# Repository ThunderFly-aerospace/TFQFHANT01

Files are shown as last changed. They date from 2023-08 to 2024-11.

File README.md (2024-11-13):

# TFQFHANT01 - Lightweight 3D-Printed Quadrifilar Helix Antenna for Telemetry

The **TFQFHANT01** module is a lightweight, 3D-printable Quadrifilar Helix (QFH) antenna designed for telemetry transmission from unmanned platforms, such as high-altitude stratospheric balloons. This design leverages a hemispherical, circularly polarized radiation pattern ideal for consistent communication with ground stations, particularly during varying orientations and altitude shifts typical of balloon trajectories.

Light 3D-printed QFH antenna design

## Design and Construction

The antenna structure is composed of two 0.8mm silver-plated copper wires with lengths of **357 mm** and **339.4 mm**, respectively. These wires form the QFH loops and are fixed within a 3D-printed PLA framework to maintain accurate geometry, which is crucial for proper circular polarization and tuning. The antenna loops connect to the **QFHBAL01** balun module via soldered joints, ensuring a stable feed point with minimal signal loss.

The 3D-printed model is parametrically designed in [OpenSCAD](https://openscad.org/), allowing for easy adjustments to the antenna's dimensions and shape to meet specific frequency band and application requirements.

### Key Components

- **Antenna Material**: 0.8 mm silver-plated copper wire
- **Total Length of Helices**: 357 mm and 339.4 mm
- **3D-Printed Framework**: PLA material for lightweight and rigid support
- **Antenna Balun**: [QFHBAL01 PCB](https://github.com/mlab-modules/QFHBAL01) for balanced feed and improved impedance matching
- **Connector Compatibility**: RG174 coaxial cable with MCX or SMA connectors

## Frequency Tuning

This antenna is designed to operate at **868 MHz** but requires adjustment to compensate for parasitic capacitance introduced by the 3D model. The antenna was optimized by calculating its parameters for a higher target frequency (913 MHz) to achieve resonance at 868 MHz. Any modifications to antenna dimensions or materials should be re-validated through measurement to ensure proper tuning.

Frequency response
Smith Chart
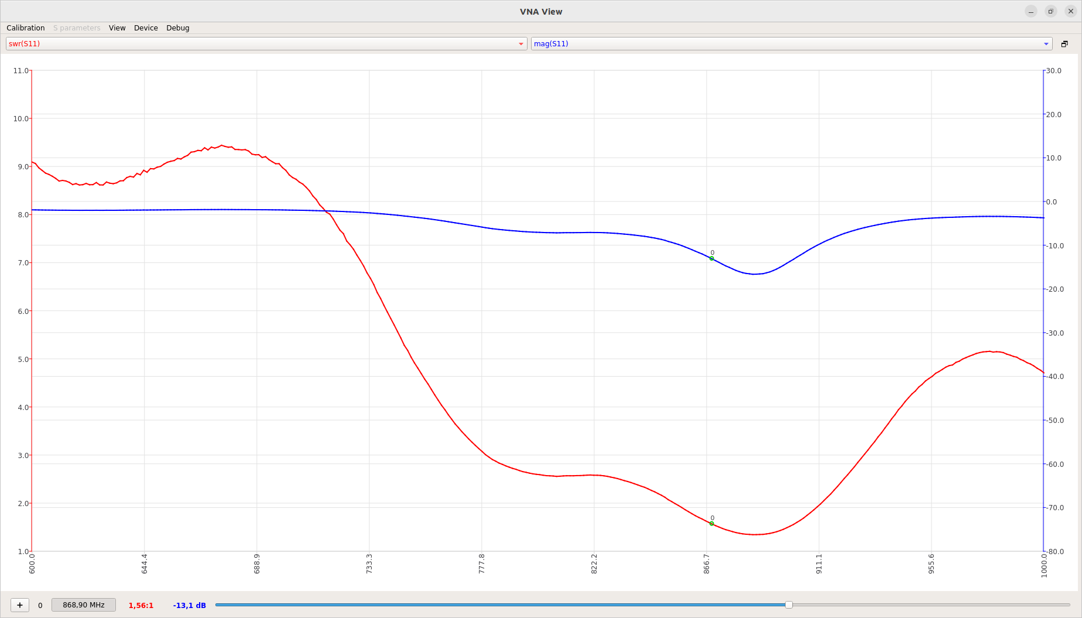
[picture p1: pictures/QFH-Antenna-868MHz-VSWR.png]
VSWR


Calculations were conducted using [JCoppens’ QFH Calculator](http://jcoppens.com/ant/qfh/calc.en.php).

## Applications

This lightweight QFH antenna is optimized for high-altitude telemetry in stratospheric balloon applications, providing robust, circularly polarized transmission that is resilient to changes in the balloon’s orientation. Its circular polarization helps maintain reliable communication with ground-based receivers across a wide field of view, which is critical during balloon ascent, drift, and descent phases.

## Assembly Notes

- **Antenna Feed Point**: The QFHBAL01 balun offers a stable feed point with balanced impedance, supporting easy integration with coaxial cables. For optimum performance, verify feed-point alignment and secure all soldered connections.
- **Frequency Response Adjustment**: The inherent capacitance of the 3D-printed structure may affect resonance. Fine-tuning adjustments may be necessary if deviations from the calculated dimensions occur.

### Safety and Usage Notice

Adjustments to any parameters, including wire lengths or balun connection configurations, should be verified through measurements to maintain the intended performance characteristics. 

For detailed explanations of the QFH parameters and additional information, refer to [this resource](https://uuki.kapsi.fi/qha_simul.html).

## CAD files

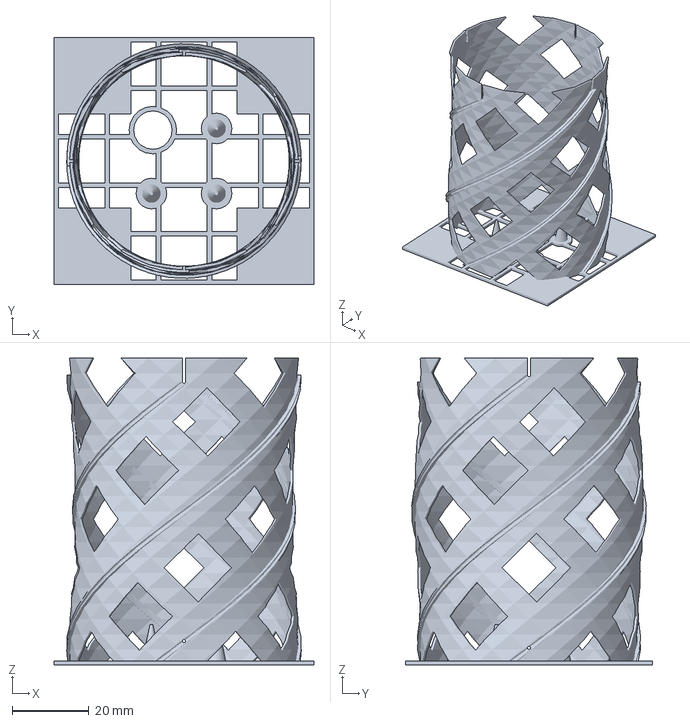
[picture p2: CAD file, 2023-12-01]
QFH-Antenna.3mf
67.7 x 64.4 x 80.0 mm

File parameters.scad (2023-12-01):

// -------------------------------------------------------------
// Parameters valid for 433MHz ISM band antenna
//
// -------------------------------------------------------------
// Dimensions calculated with John Coppens webpage java script
// @ http://jcoppens.com/ant/qfh/calc.en.php
// Input params:
// Center frequency = 433 MHz  (443.4 MHz designed)
// Numbers of turns = 0.5
// Length of one turn = 1 lambda
// Bending radius = 2 mm
// Conductor diameter = 0.6 mm
// Width/height ratio = 0.84
//
// -------------------------------------------------------------
/*
$fn=20;


D1 = 123.2; // mm large helix1 diameter.
D2 = 117.1; // mm small helix2 diameter.
HH1 = 146.6; // mm height of H1.
HH2 = 139.4; // mm height of H2.

WIRE = 1; // mm diameter.

CYLH = 150; // mm height of support cylinder.
SLICES = 20;
EXTRUSION_WIDTH=0.67;
pedestal_height = 1;

*/

//####################################################################################

// -------------------------------------------------------------
// Parameters valid for 868MHz ISM band antenna
//
// Dimensions calculated with John Coppens webpage java script
// @ http://jcoppens.com/ant/qfh/calc.en.php
// Input params:
// Center frequency = 913 MHz
// Numbers of turns = 0.5
// Length of one turn = 1
// Bending radius = 1.5 mm
// Conductor diameter = 0.6 mm
// Width/height ratio = 0.44
//
// -------------------------------------------------------------


/*$fn=20;

D1 = 47.4; // mm large helix1 diameter.
D2 = 45.1; // mm small helix2 diameter.
HH1 = 107.9; // mm height of helix1.
HH2 = 102.6; // mm height of helix2.

WIRE = 1; // mm diameter.

CYLH = 118; // mm height of support cylinder.

SLICES = 20;
EXTRUSION_WIDTH=0.67;
pedestal_height = 1;
*/

// More robust lower variant

// Dimensions calculated with John Coppens webpage java script
// @ http://jcoppens.com/ant/qfh/calc.en.php
// Input params:
// Center frequency = 907.8 MHz
// Numbers of turns = 0.5
// Length of one turn = 1
// Bending radius = 1.5 mm
// Conductor diameter = 0.6 mm
// Width/height ratio = 0.85
//
// -------------------------------------------------------------


$fn=20;

D1 = 60.5; // mm large helix1 diameter.
D2 = 57.5; // mm small helix2 diameter.
HH1 = 71.1; // mm height of helix1.
HH2 = 67.6; // mm height of helix2.

WIRE = 0.8; // mm diameter.

CYLH = 80; // mm height of support cylinder.

SLICES = 20;
EXTRUSION_WIDTH=0.67;
pedestal_height = 1;
ThornsRot = 0; // standard feedpoint 
//ThornsRot = 90; // anit-standard feedpoint 

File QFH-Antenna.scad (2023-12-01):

// OpenSCAD script for a "quadrifilar helix antenna".
// The design originated in: http://www.thingiverse.com/thing:634205

PI = 3.14159265358979;

include <parameters.scad>

CYLH2 = CYLH/2; // the half-height of the support cylinder.

HWIRE11 = CYLH2-HH1/2; // place the four hole-pairs at these heights.
HWIRE12 = CYLH2-HH2/2;
HWIRE21 = CYLH2+HH1/2;
HWIRE22 = CYLH2+HH2/2;

lightening_hole_size = (D1 * PI)/15;
lightening_hole_num = floor(CYLH/lightening_hole_size);

// some internal calculations. quite hairy math.
THETA1 = atan2(HH1,D1*PI/2); // Thetas are used for projecting the wirechannel cross-section onto the xy-plane.
THETA2 = atan2(HH2,D2*PI/2);
echo("theta1=",THETA1,"  -  theta2=",THETA2);

XSI1 = ((CYLH/HH1*180)-180); // extra rotation beyond the height of helix1. half above, half below.
XSI2 = ((CYLH/HH2*180)-180); // extra rotation beyond the height of helix2.
echo("xsi1=",XSI1," - xsi2=",XSI2);



//------------ Safety grid parameters---------------------------

nY = 5;
nX = 5;


meshX=D1*1.1;
meshY=D2*1.1;

CornerSquareSize = 20;

// width of solid part of grid
meshSolid=1.2;

meshSpaceX = (meshX - meshSolid*nX)/nX;
meshSpaceY = (meshY - meshSolid*nY)/nY;

// Addition of circles with thorns - parameters

    ThornsDist = 16.9706;
    ThornCircleRad = 4;
    ThornHeight = 10;
    ThornLowerBaseRad = 2.5;
    ThornUpperBaseRad = 0.4;

CoaxHoleRad = 5;  // Radius of hole for coaxial cable


module base(){
 difference(){
    union()
    {
        for (i=[0:nX]) {
                 translate([i*(meshSolid+meshSpaceX) - meshSolid/2,0,0]) cube(size=[meshSolid, meshY, pedestal_height],center=false);
        }

        for (i=[0:nY]) {
                translate([0,i*(meshSolid+meshSpaceY) - meshSolid/2,0]) cube(size=[meshX, meshSolid, pedestal_height],center=false);

        }

    // Addition of solid squares in corners
        translate([- meshSolid/2,- meshSolid/2,0])
        cube([CornerSquareSize,CornerSquareSize,pedestal_height]);

        translate([nX*(meshSolid+meshSpaceX)+ meshSolid/2-CornerSquareSize,- meshSolid/2,0])
        cube([CornerSquareSize,CornerSquareSize,pedestal_height]);

        translate([nX*(meshSolid+meshSpaceX)+ meshSolid/2-CornerSquareSize,nY*(meshSolid+meshSpaceY)+ meshSolid/2-CornerSquareSize,0])
        cube([CornerSquareSize,CornerSquareSize,pedestal_height]);

        translate([- meshSolid/2,nY*(meshSolid+meshSpaceY)+ meshSolid/2-CornerSquareSize,0])
        cube([CornerSquareSize,CornerSquareSize,pedestal_height]);

    // Addition of circles with thorns

    translate([nX*(meshSolid+meshSpaceX)/2, nY*(meshSolid+meshSpaceY)/2,pedestal_height/2]) // Grid center
    rotate([0,0,ThornsRot])
    {
    translate([ThornsDist/2, ThornsDist/2,0])
        union(){
        cylinder(pedestal_height,ThornCircleRad,ThornCircleRad,center = true);
        translate([0,0,ThornHeight/2])
        cylinder(ThornHeight, ThornLowerBaseRad,ThornUpperBaseRad, true);
        }
    translate([ThornsDist/2, -ThornsDist/2,0])
        union(){
        cylinder(pedestal_height,ThornCircleRad,ThornCircleRad,center = true);
        translate([0,0,ThornHeight/2])
        cylinder(ThornHeight, ThornLowerBaseRad,ThornUpperBaseRad, true);
        }

    translate([-ThornsDist/2, -ThornsDist/2,0])
        union(){
        cylinder(pedestal_height,ThornCircleRad,ThornCircleRad,center = true);
        translate([0,0,ThornHeight/2])
        cylinder(ThornHeight, ThornLowerBaseRad,ThornUpperBaseRad, true);
        }


    }
// Hole for coaxial cable - part 1
 translate([nX*(meshSolid+meshSpaceX)/2, nY*(meshSolid+meshSpaceY)/2,pedestal_height/2])
  rotate([0,0,ThornsRot])
   translate([-16.22/2, 16.1/2,0])
    cylinder(pedestal_height,CoaxHoleRad+meshSolid,CoaxHoleRad+meshSolid,center = true);

    }

 // Hole for coaxial cable - part 2
  translate([nX*(meshSolid+meshSpaceX)/2, nY*(meshSolid+meshSpaceY)/2,pedestal_height/2])
  rotate([0,0,ThornsRot])
   translate([-16.22/2, 16.1/2,-1])
    cylinder(pedestal_height+3,CoaxHoleRad,CoaxHoleRad,center = true);

  }
}

// definition of the wire channel by CSG.
// used for projecting outline onto the xy-plane.
module wirechannel()
{
	difference()
	{
        translate([-0.5,0,0])
		cube(size = [2*WIRE, 2*WIRE,2], center=true);

        cylinder(h=2, d=WIRE, center=true);

		translate([1.5*WIRE,0,0])
            cube([3*WIRE,WIRE,4], center=true);
	}
}

// definition of elliptic cylinder by CSG.
// used for projecting outline onto xy-plane.
module ellipse_base()
{
	scale([1,D2/D1,1])
        difference(){
            cylinder(h=1, r=(D1/2-WIRE/2), center = true);
            cylinder(h=2, r=(D1/2 - WIRE/2 - EXTRUSION_WIDTH), center = true);
        }
}

// the composite structure of support cylinder, wire channels, holes and cut-outs.
module composite()
{
	difference()
	{
		union()
		{
			// combine all elements in one extrude and twist.
			// helix1's.
			linear_extrude(height=HWIRE21, twist=-XSI1/2-180, slices=SLICES)
			{
				rotate([0,0,0-XSI1/2])
                    translate([D1/2,0,0])
                        projection()
                            scale([1,1/sin(THETA1),1])
                                wirechannel();

				rotate([0,0,180-XSI1/2])
                    translate([D1/2,0,0])
                        projection()
                            scale([1,1/sin(THETA1),1])
                                wirechannel();
			}
			// helix2's.
			linear_extrude(height=HWIRE22, twist=-XSI2/2-180, slices=SLICES)
			{
				rotate([0,0,90-XSI2/2])
                    translate([D2/2,0,0])
                        projection()
                            scale([1,1/sin(THETA2),1])
                                wirechannel();

				rotate([0,0,270-XSI2/2])
                    translate([D2/2,0,0])
                        projection()
                            scale([1,1/sin(THETA2),1])
                                wirechannel();
			}
			// elliptic support cylinder.
			linear_extrude(height=CYLH, twist=-XSI1/2-180, slices=SLICES)
			{
				rotate([0,0,0-XSI1/2]) projection(cut=true) ellipse_base();
			}
		}
		union()
		{
			// lower hole pairs.
			translate([0,0,HWIRE11])
                rotate([0,90,0])
                color([0,0,1])
                    cylinder(h=D1, d=WIRE, center=true);

			translate([0,0,HWIRE12])
                rotate([90,0,0])
                color([0,1,0])
                    cylinder(h=D2, d=WIRE, center=true);

			// upper hole slots.
      // large loop (blue)
			translate([0,0,HWIRE21])
                rotate([0,90,0])
                  color([0,0,1])
                    cylinder(h=D1, d=WIRE, center=true);

      // small loop (green)
			translate([0,0,HWIRE22])
                rotate([90,0,0])
                color([0,1,0])
                    cylinder(h=D2, d=WIRE, center=true);

			translate([0,0,HWIRE21+CYLH2]) cube([CYLH,WIRE,CYLH], center=true);
			translate([0,0,HWIRE22+CYLH2]) cube([WIRE,CYLH,CYLH], center=true);

            for (i=[0:lightening_hole_num]) {
                translate([0,0,i*lightening_hole_size])
                    rotate([0,0, +45 - XSI1/2 + i * ((180+XSI1/2)/(lightening_hole_num))])
                        rotate([45,0,0])
                            cube(size = [D1,lightening_hole_size,lightening_hole_size],center=true);

            }

            for (i=[0:lightening_hole_num]) {
                translate([0,0,i*lightening_hole_size])
                    rotate([0,0, -45 -XSI2/2 + i * ((180+XSI2/2)/lightening_hole_num)])
                        rotate([45,0,0])
                            cube(size = [D1,lightening_hole_size,lightening_hole_size],center=true);

            }


		}
	}
	translate([-meshX/2,-meshY/2,0])
		base();
}

//wirechannel();
//ellipse_base();
//base();

// MAIN()
composite();


// QFHBAL Dimensions
#linear_extrude(height = 5, center = true)
    rotate([0,0,-45-90])
		  import(file = "QFHBAL01/hw/cam_profi/QFHBAL01-User_Comments.dxf");

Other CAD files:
QFH-Antenna.stl

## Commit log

2020-11-26 Parameters changed to 433 MHz ISM band antenna.
    [parameters.scad]
2020-11-26 Update QFH-Antenna.scad
    The right rotation of thorns
    [QFH-Antenna.scad]
2020-11-27 Redered new STL for 433 MHz antenna variant.
    [QFH-Antenna.stl]
2023-12-01 Fix wrong feed point orientation for downward radiating HAB antenna.
    [QFH-Antenna.scad, QFH-Antenna.stl, parameters.scad]
2023-12-01 Create prusaslicer project for 868 MHz antenna variant.
    [QFH-Antenna.3mf]
2024-11-11 Add photos of antenna mounted on the balloon gondola.
